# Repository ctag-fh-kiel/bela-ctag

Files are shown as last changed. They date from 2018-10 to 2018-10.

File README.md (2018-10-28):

## Resources regarding [CTAG-audio](http://ctag-audio.de/) capes for BeagleBone single board computers.

See [Wiki](https://github.com/ctag-fh-kiel/bela-ctag/wiki) for getting started with native Linux applications and CTAG multi-audio boards.

*CTAG multi-audio IO capes are compatible with the ultra-low-latency [Bela platform](http://bela.io/) and are available via [Bela's online shop](https://shop.bela.io/ctag).*

## Open source hardware resources include: 
- Schematic in pdf 
- Kicad 4.0.7 project data (PCB does not contain routed copper layers at this point --> will be added after some time together with BOM etc.)
- Licensed under [cc-by-nc-sa-4.0](https://creativecommons.org/licenses/by-nc-sa/4.0)

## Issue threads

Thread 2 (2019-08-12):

PCB copper layers and BOM

darabi, 2019-08-12:
Are you still planning to publish the BOM and the PCB copper layers, as stated in the README?

Thanks!

ctag-fh-kiel, 2019-08-19:
Hi, thanks for your interest. We haven't discussed a timing yet...

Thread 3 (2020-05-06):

Connecting a Potentiometer via SPI Using CTAG Beast in non-BELA mode

tonylangley, 2020-05-06:
Hi,

I'm trying to interface a 10K potentiometer via a MCP3008 ADC over SPI to the Beaglebone Black running the [ctag_bone_debian_v0.1.2.img](https://github.com/ctag-fh-kiel/bela-ctag/releases/tag/v0.1.2) release.

Will this be possible or should I interface the potentiometer a different way?

Thanks in advance, Tony

ctag-fh-kiel, 2020-05-06:
Hi Tony,
You should be able to use SPI with the standard (non-bela) image. The audio codec uses bit-banged SPI through GPIO freeing up the HW SPI peripheral. If you are on the bela image SPI is blocked by bela for ADC/DAC.

Best,
Robert

tonylangley, 2020-05-06:
Thanks Robert. That’s good to know the SPI bus is free in this mode.

Any chance you could point me to any info on how to enable the SPI on this [ctag_bone_debian_v0.12](https://github.com/ctag-fh-kiel/bela-ctag/releases/tag/v0.1.2) release? I tried a few ways of doing this by updating the /boot/uEnv.txt file but couldn’t work it out!

Thanks, Tony

tonylangley, 2020-05-07:
I was able to get SPI running with the following:

`sudo sh -c "echo 'BB-SPIDEV0' > /sys/devices/platform/bone_capemgr/slots"`

tonylangley, 2020-05-07:
So I'm able to get SPI running temporarily using the command above, but I'm unable to get the SPIDEV0 device to load at boot without commenting out the following line in /boot/uEnv.txt

`dtb=am335x-boneblack-ctag-face.dtb`

This line is creating a device-tree-override which seems to prevent any subsequent uboot_overlay_options to take effect.

Once I comment this out, I can verify the SPI devices as follows:

`ls -al /dev/spi*`

As I want to use both the CTAG Beast and SPI, do you have any suggestions on how can I enable this at boot time?

henrix, 2020-05-11:
Hi,

A workaround for this would be to automatically execute the bone cape manager script

> sh -c "echo 'BB-SPIDEV0' > /sys/devices/platform/bone_capemgr/slots"

 via rc.local.

You can find some information about rc.local [here](https://www.raspberrypi.org/documentation/linux/usage/rc-local.md).

Another solution would be to enable SPIDEV in the base device tree am335x-boneblack-ctag-face.dtb. However, this would require to create a different base device trees for each required hardware configuration.

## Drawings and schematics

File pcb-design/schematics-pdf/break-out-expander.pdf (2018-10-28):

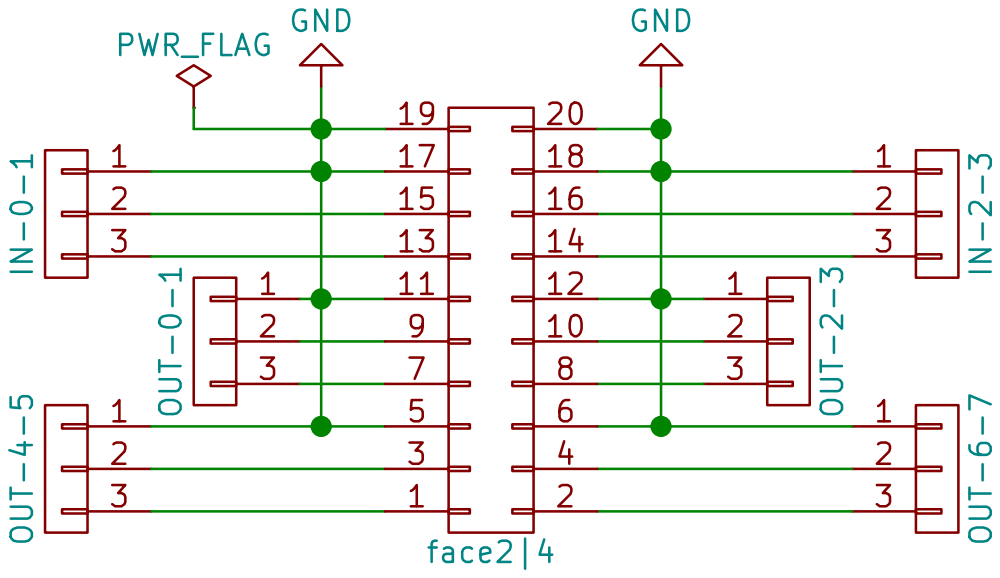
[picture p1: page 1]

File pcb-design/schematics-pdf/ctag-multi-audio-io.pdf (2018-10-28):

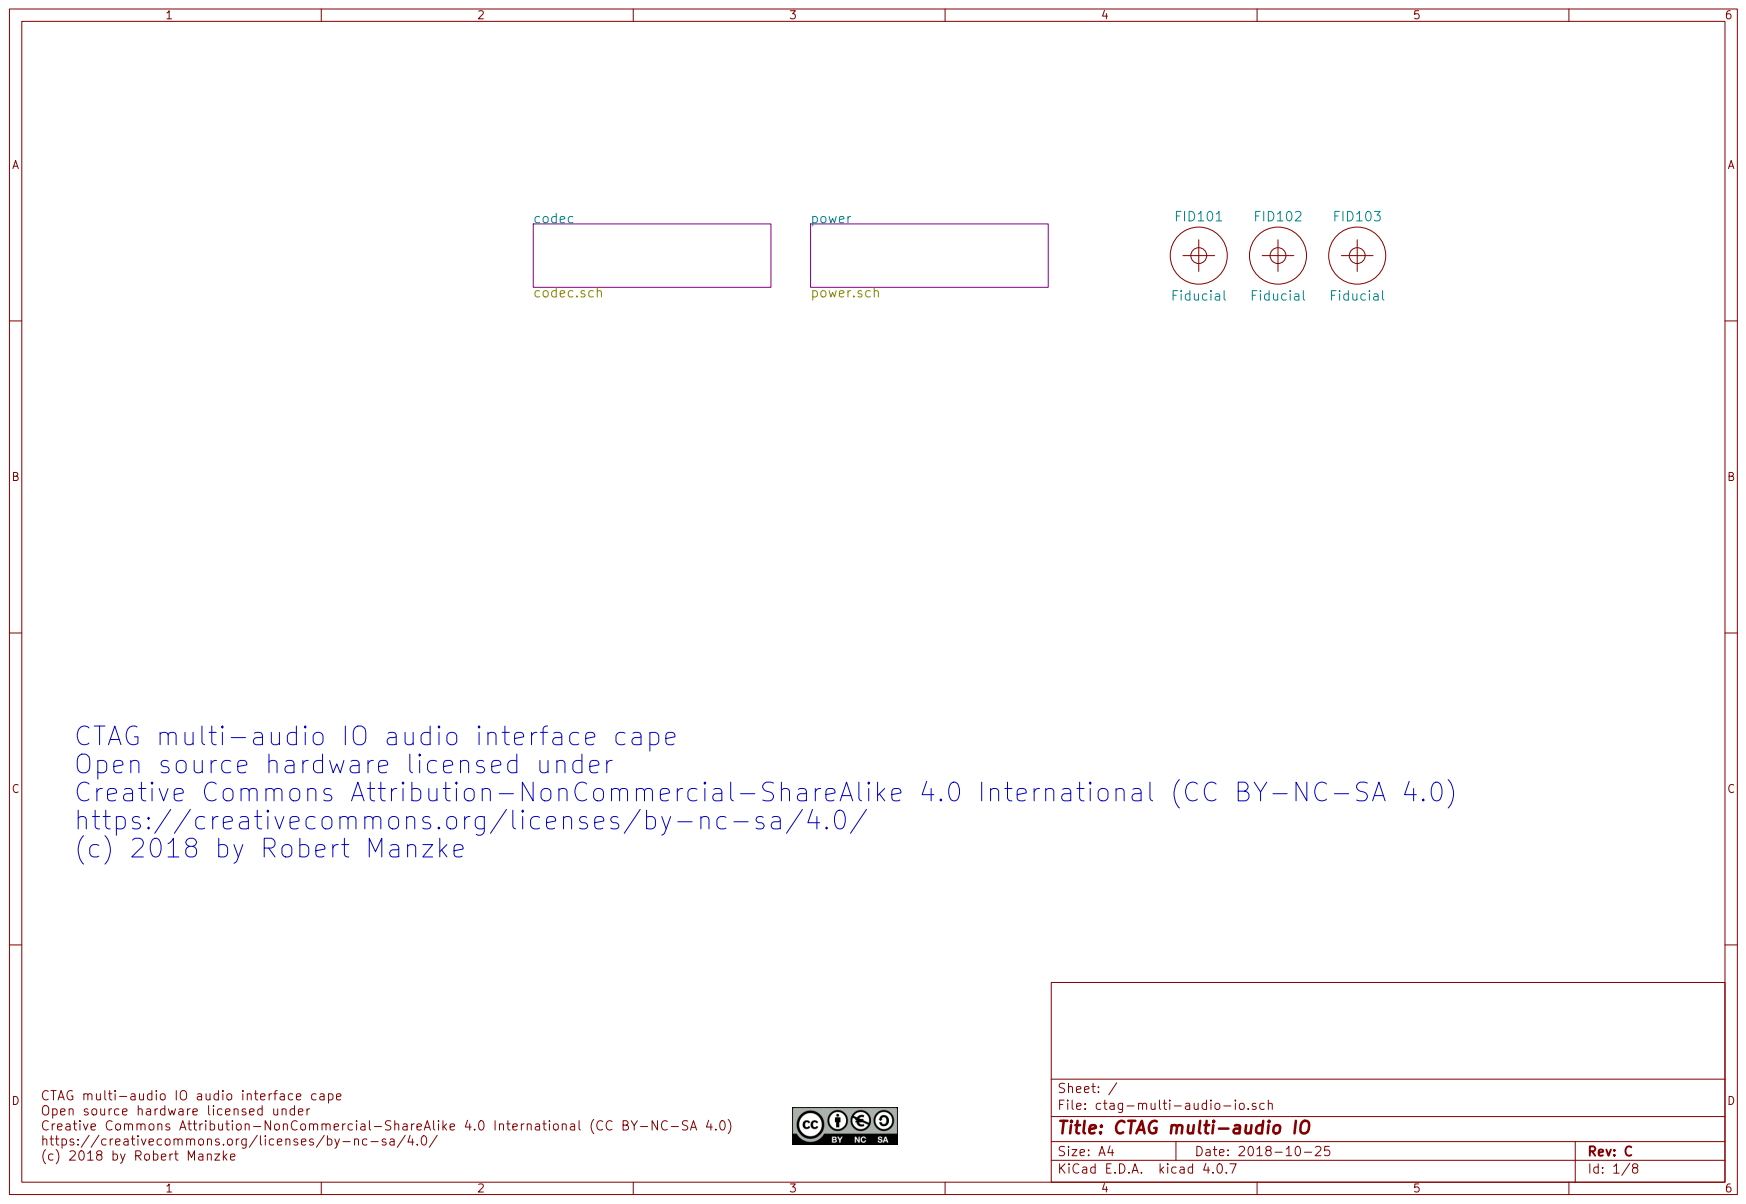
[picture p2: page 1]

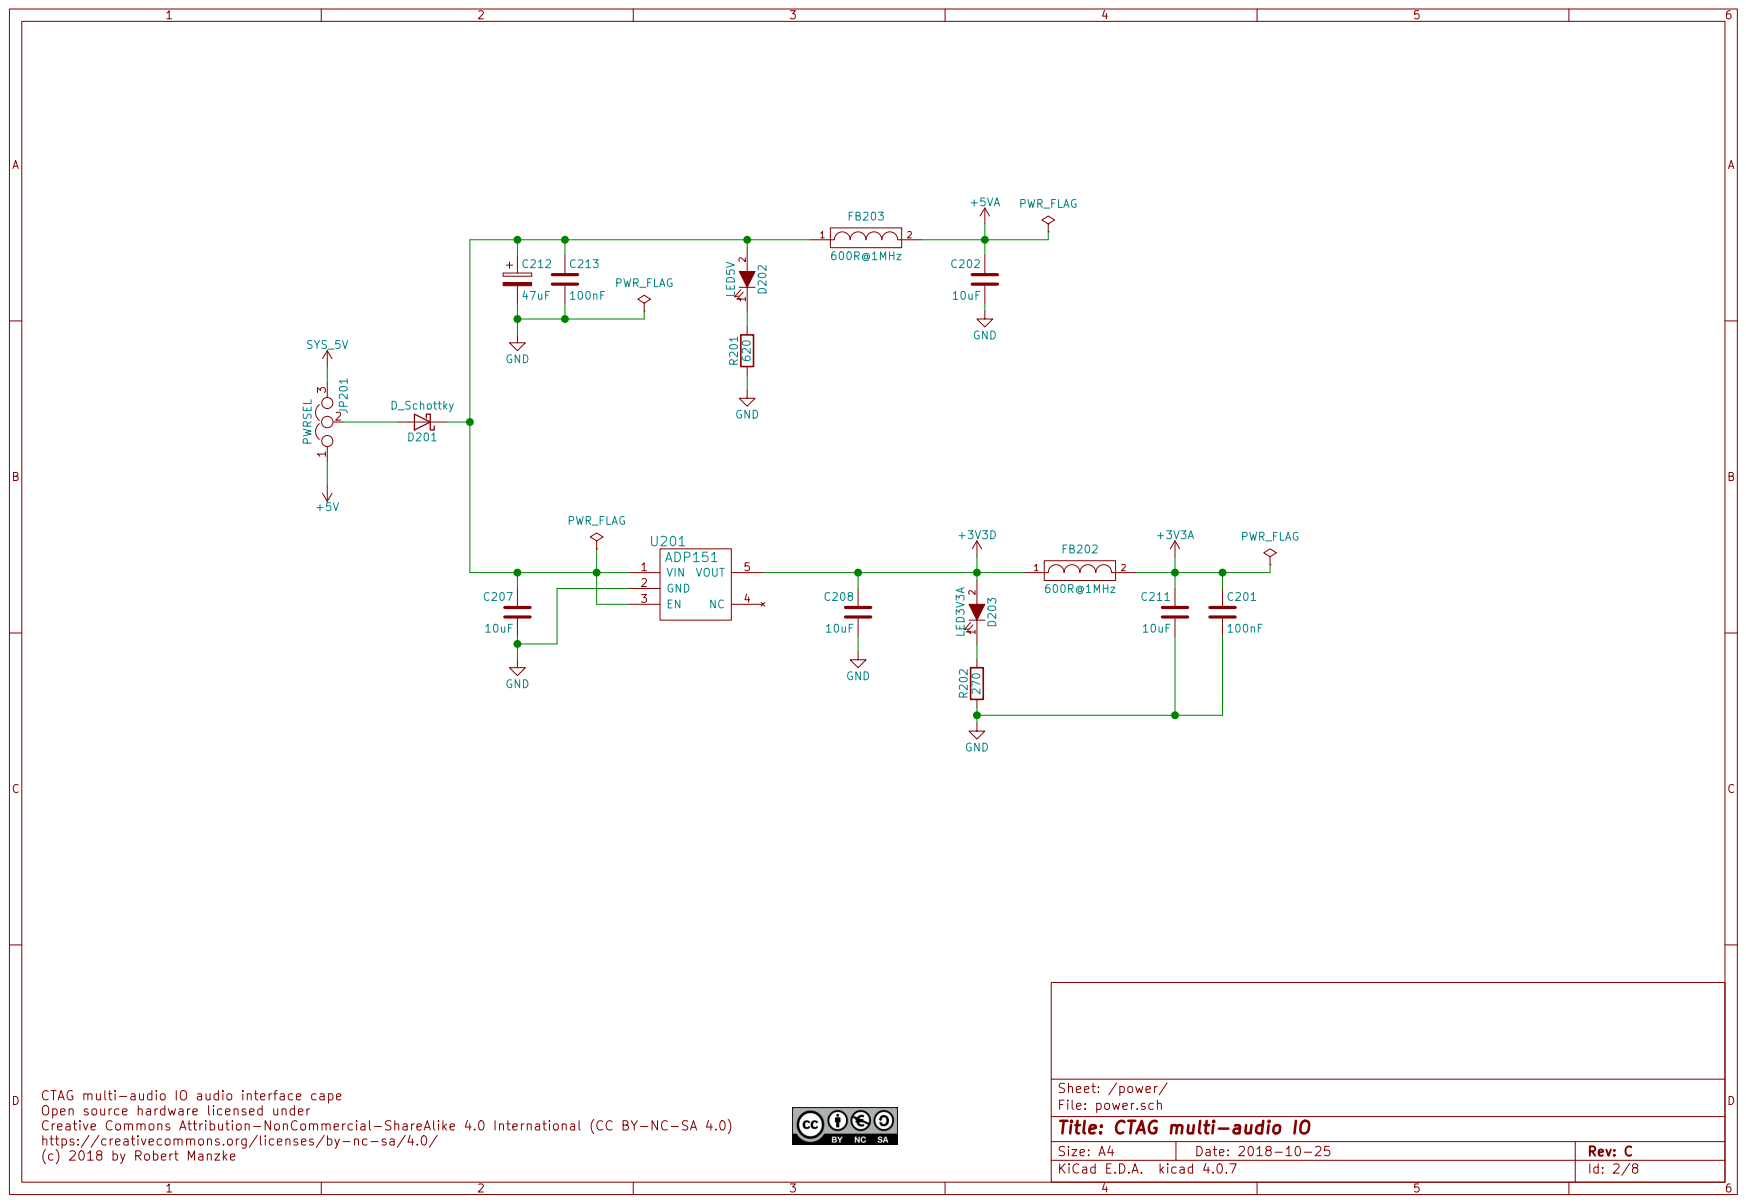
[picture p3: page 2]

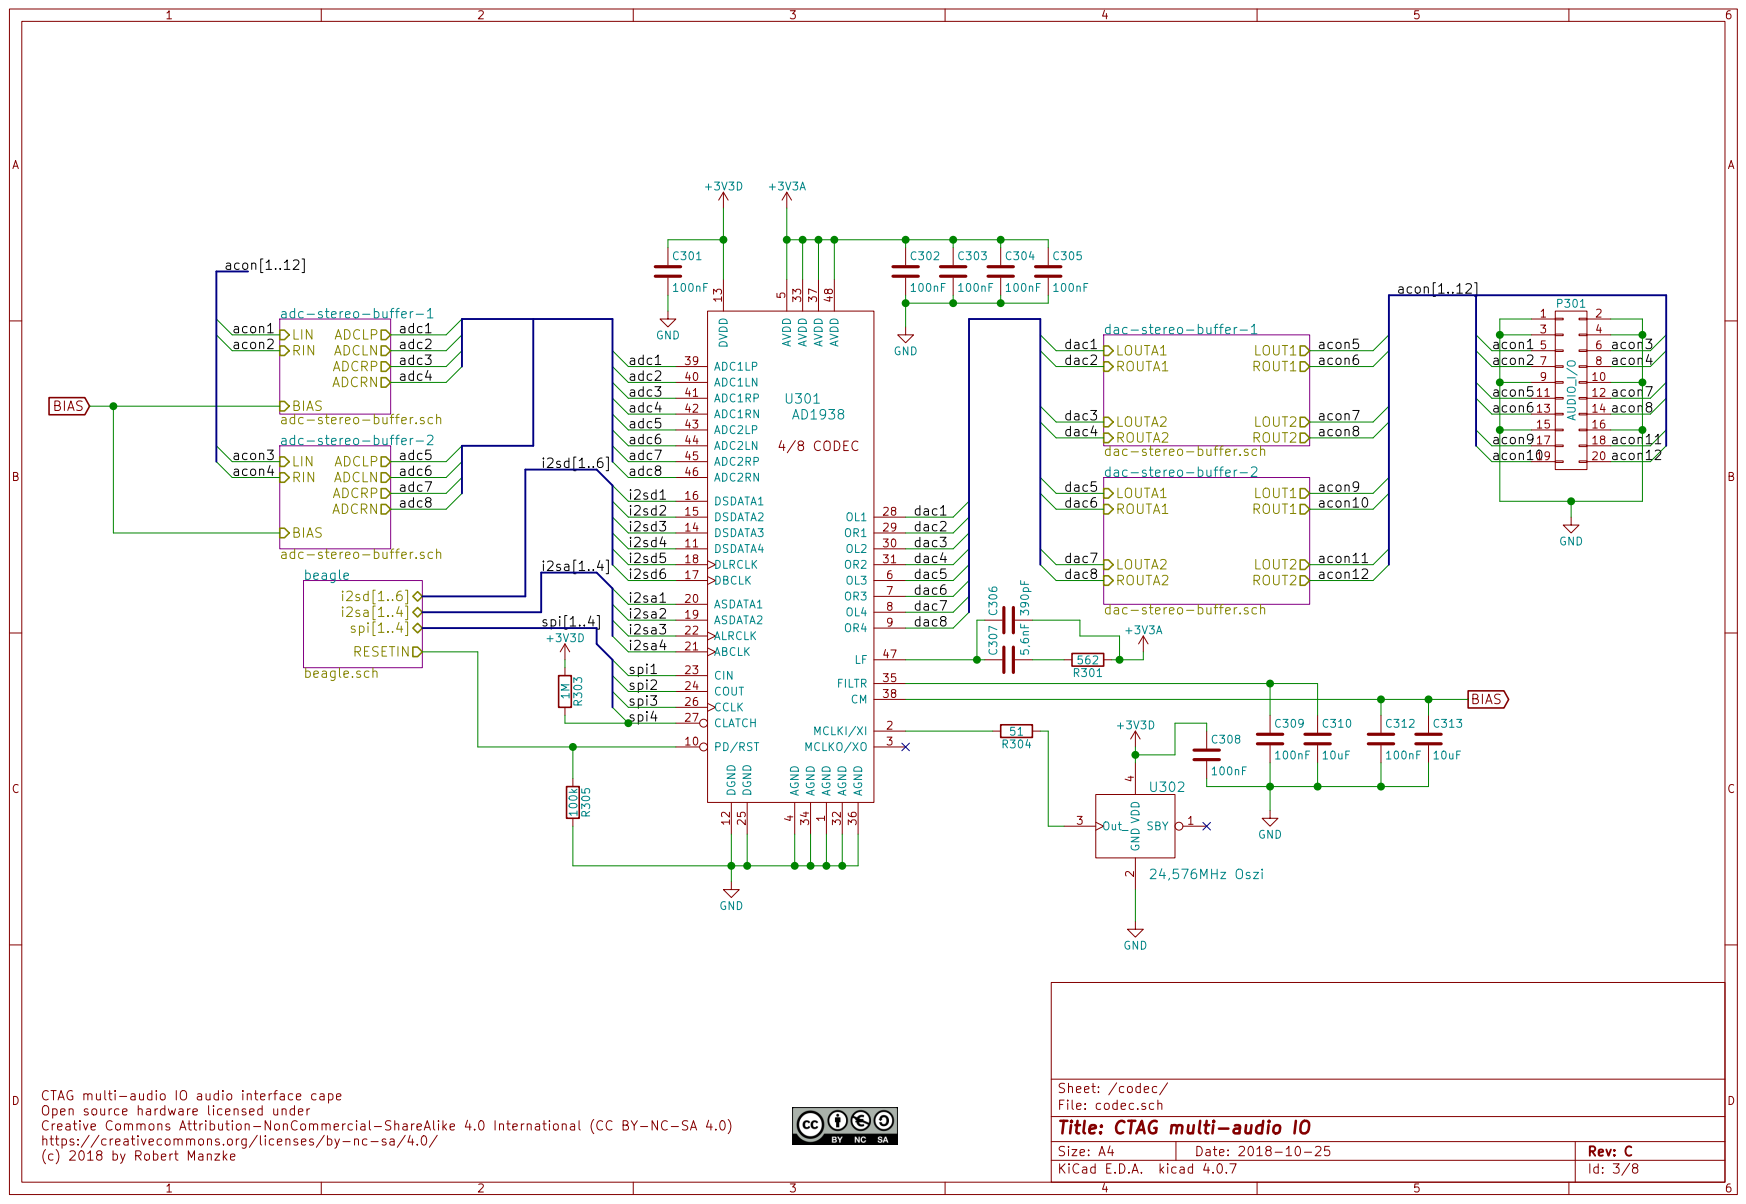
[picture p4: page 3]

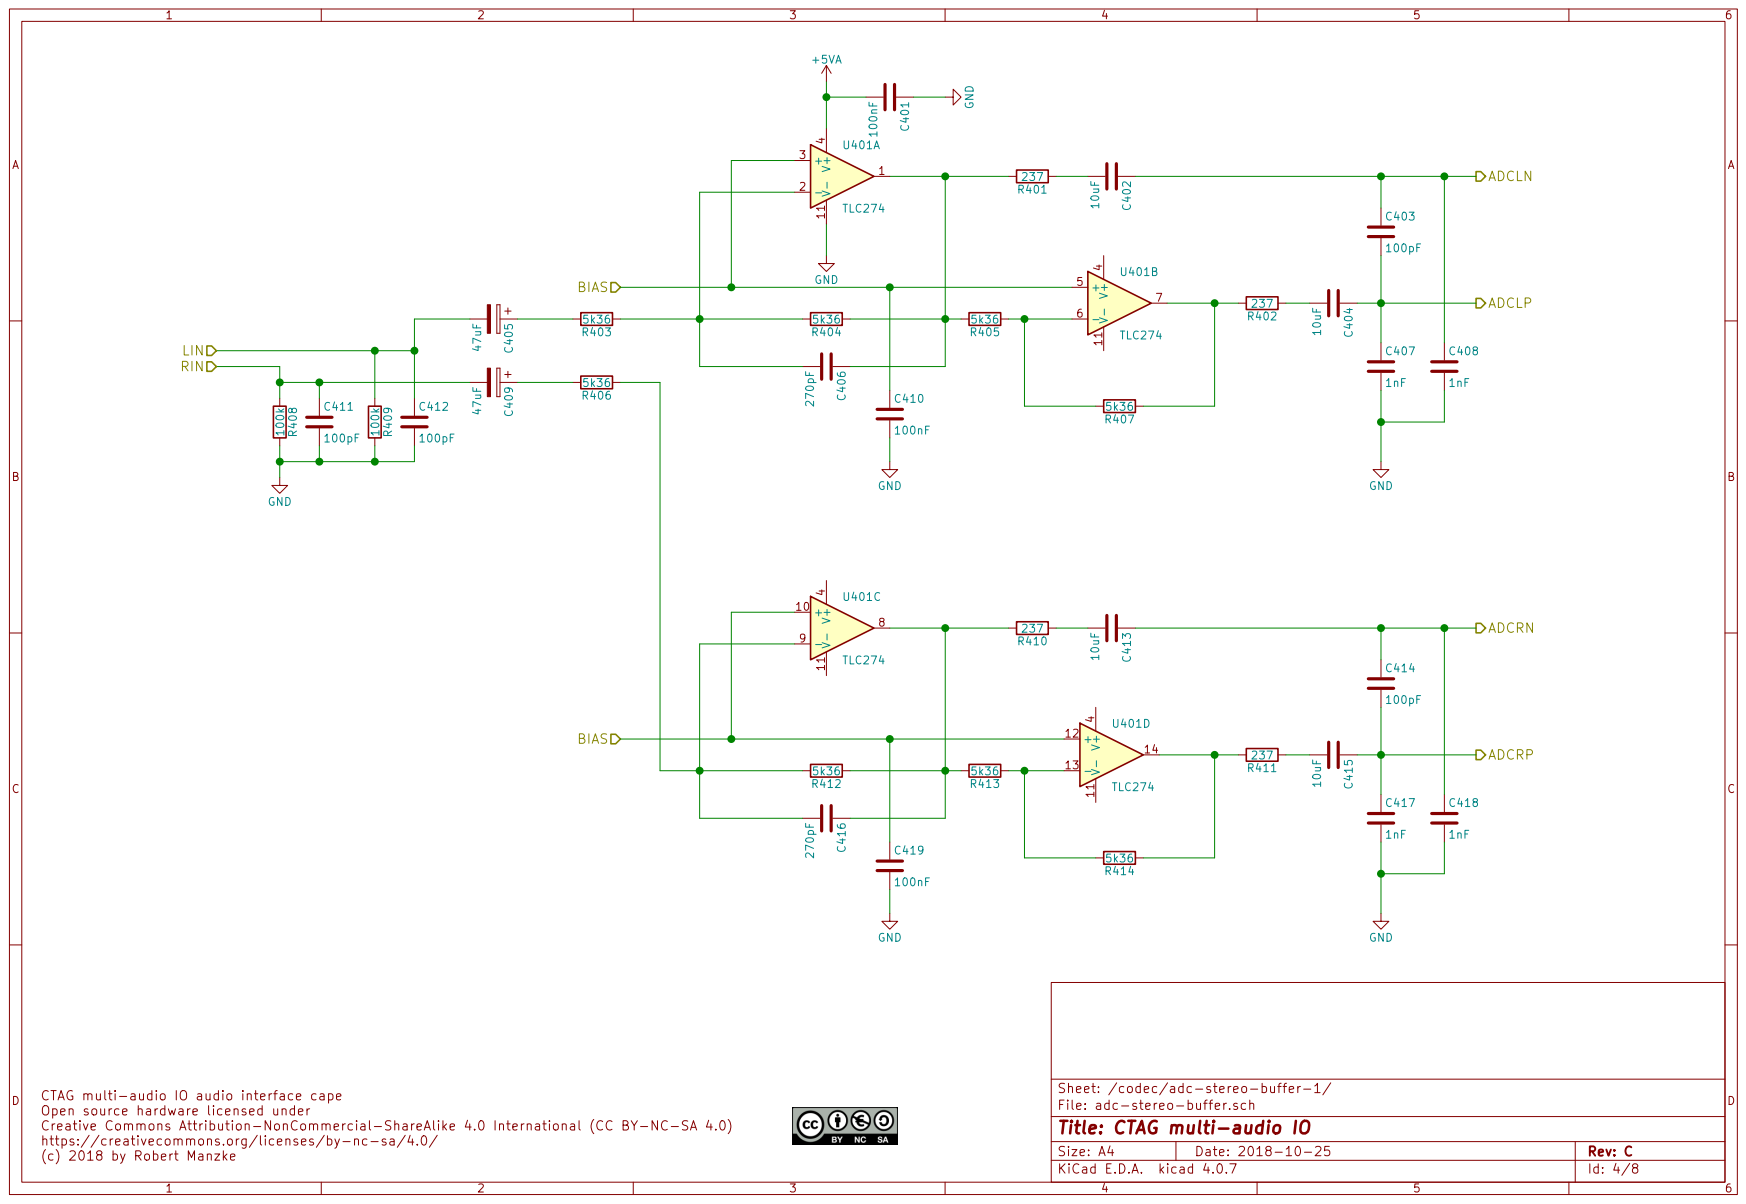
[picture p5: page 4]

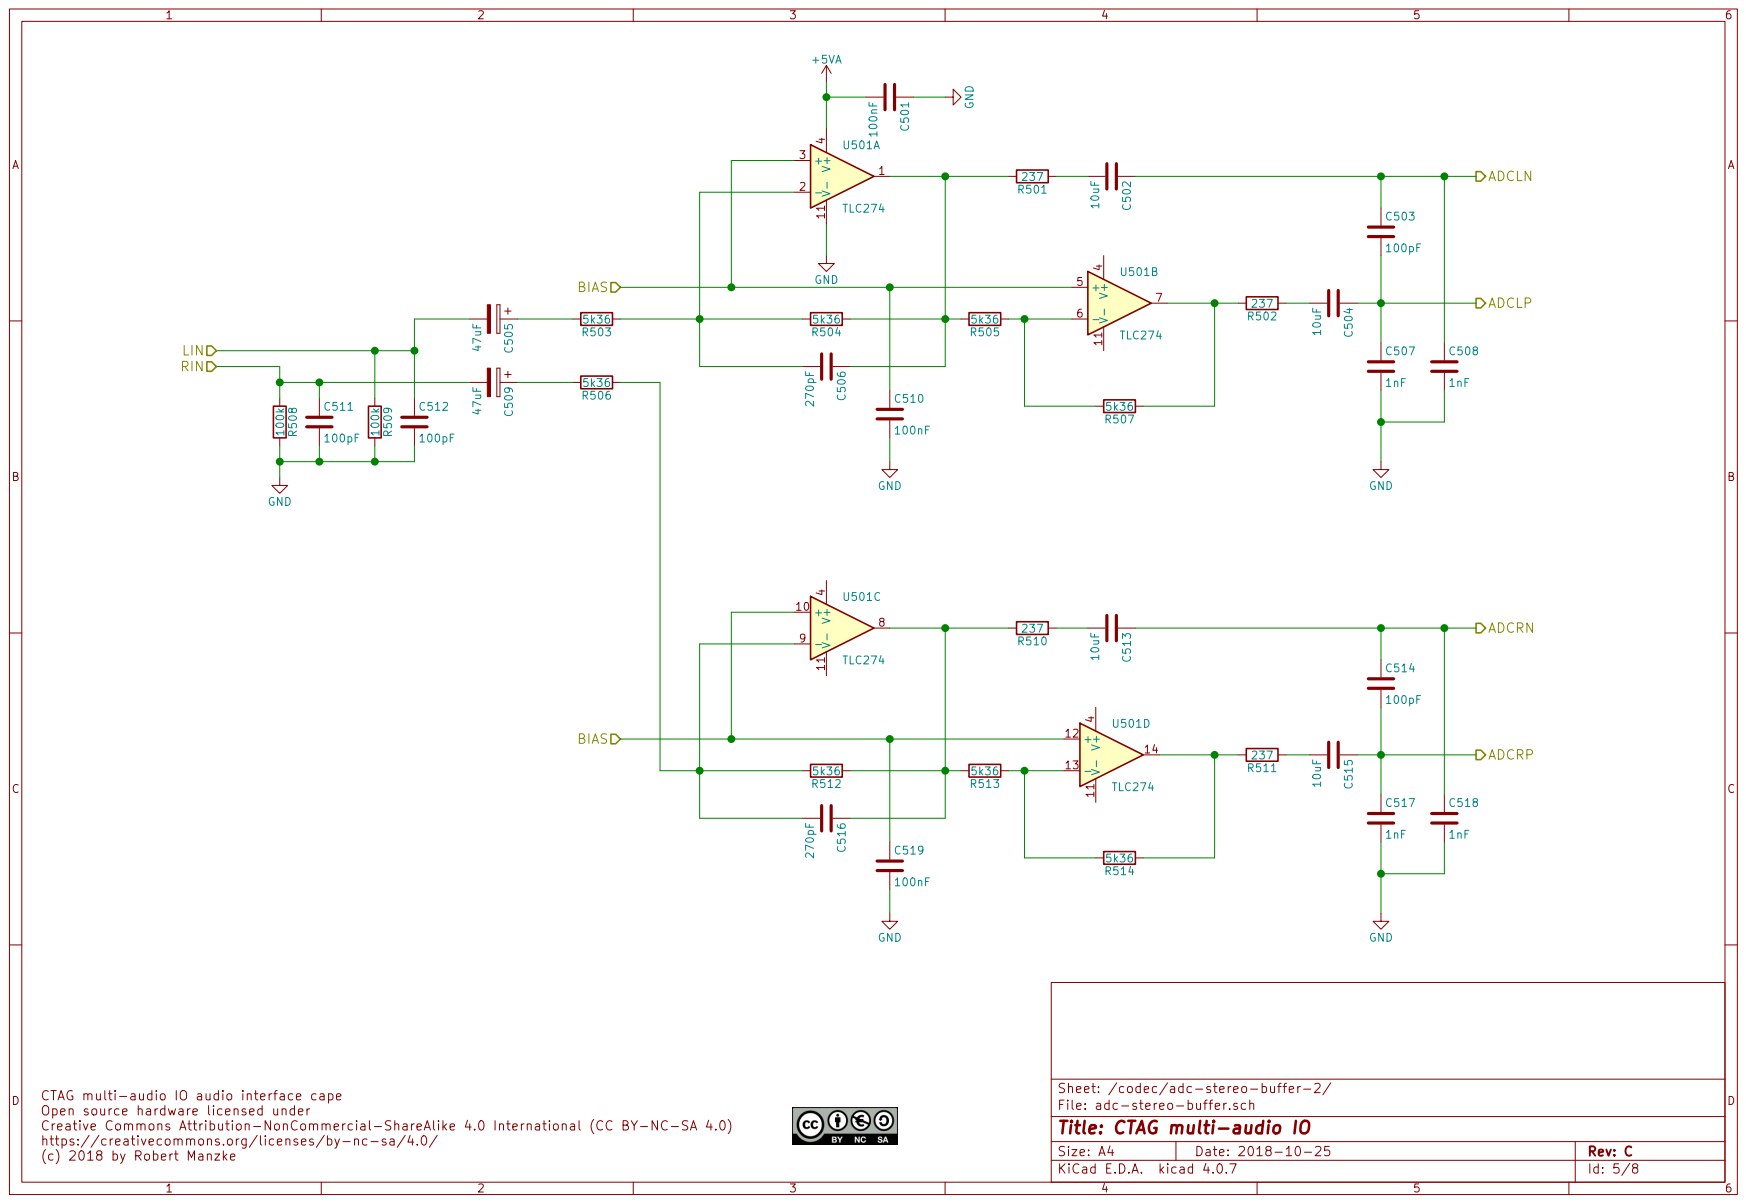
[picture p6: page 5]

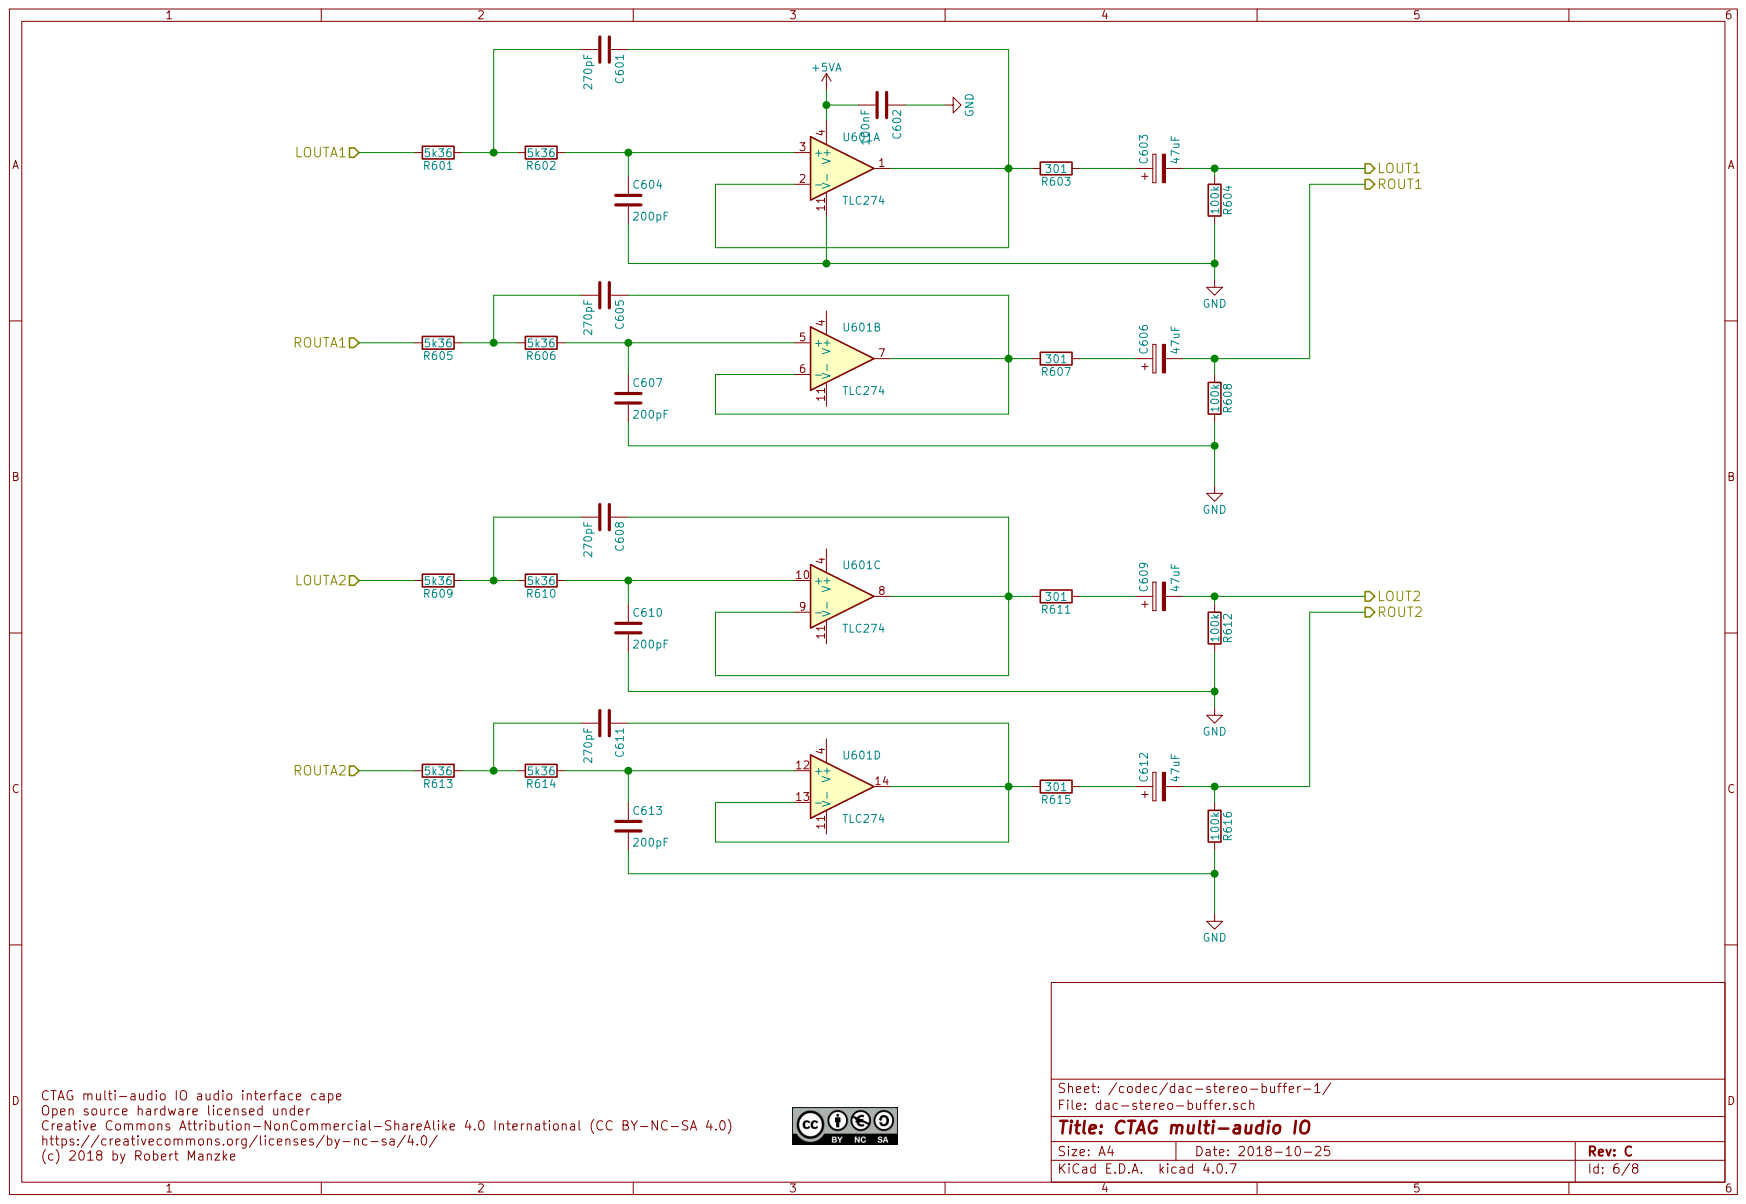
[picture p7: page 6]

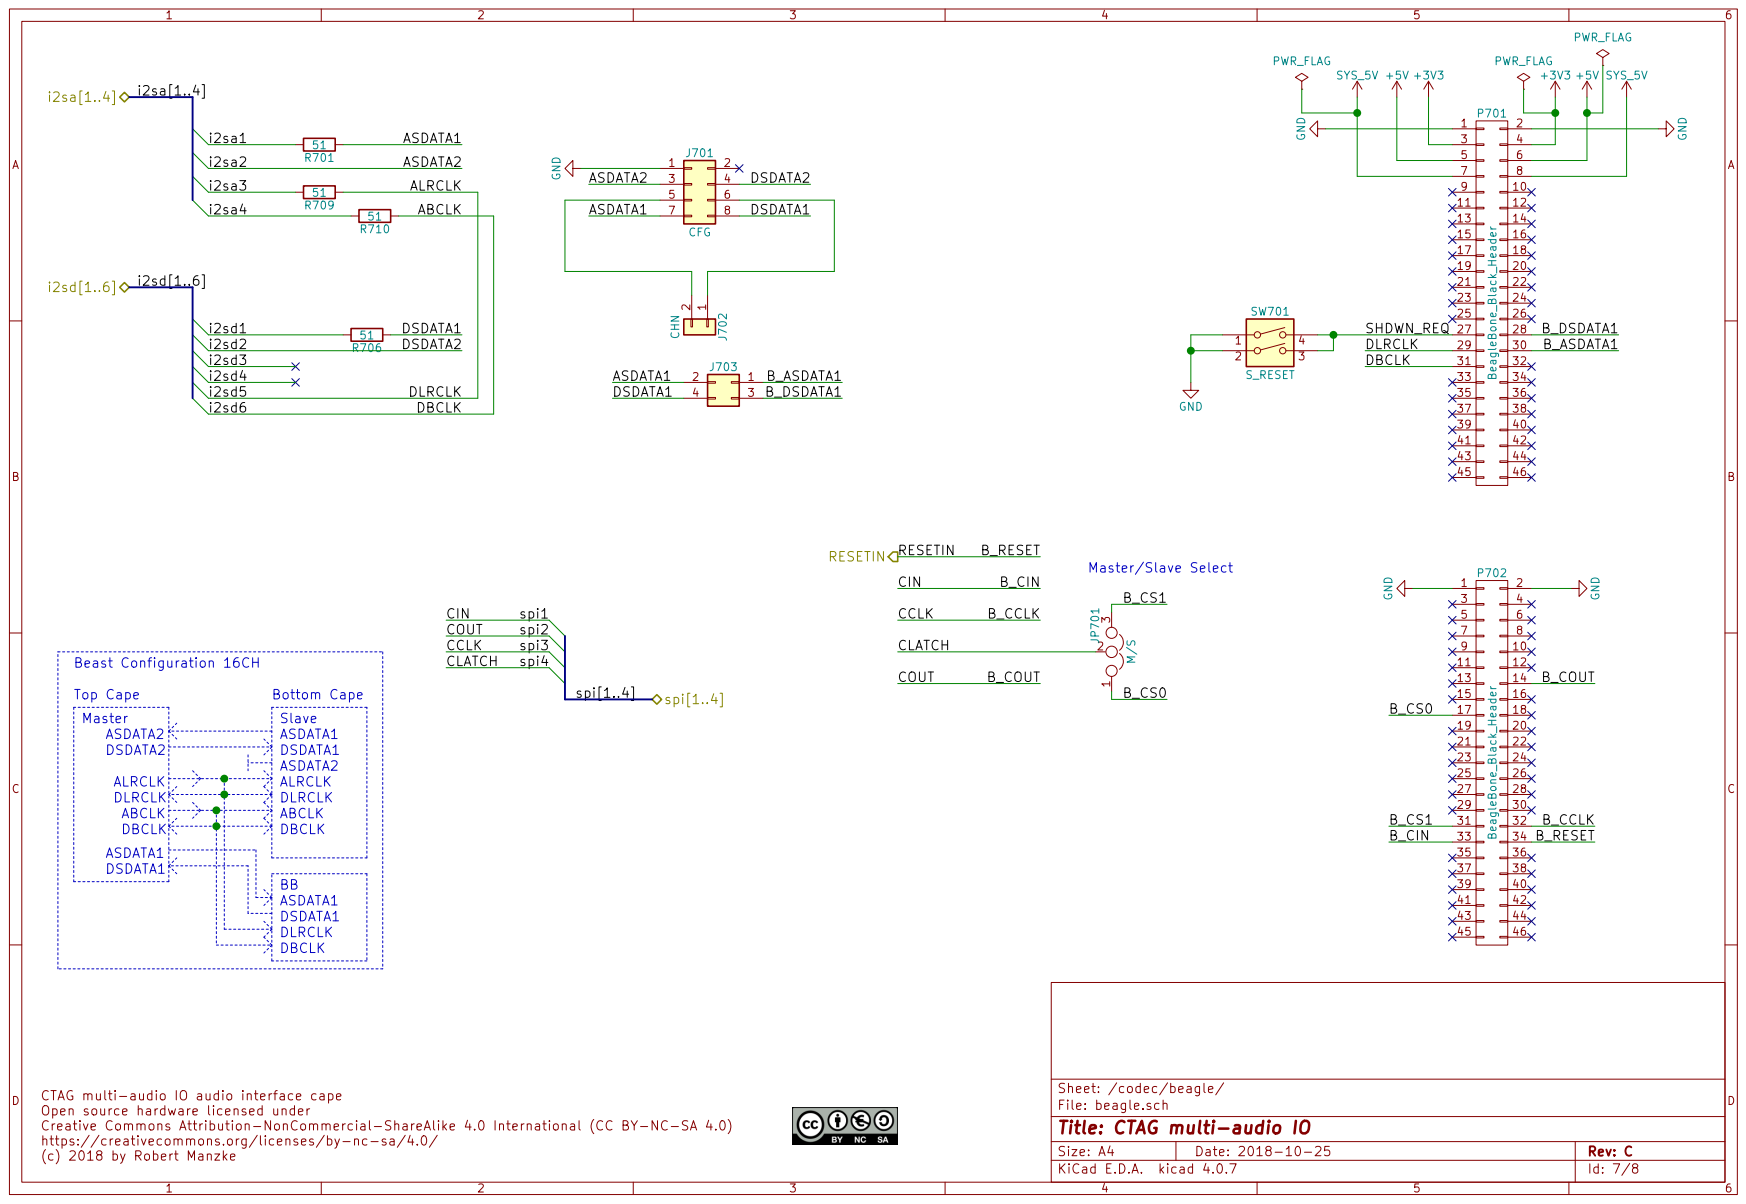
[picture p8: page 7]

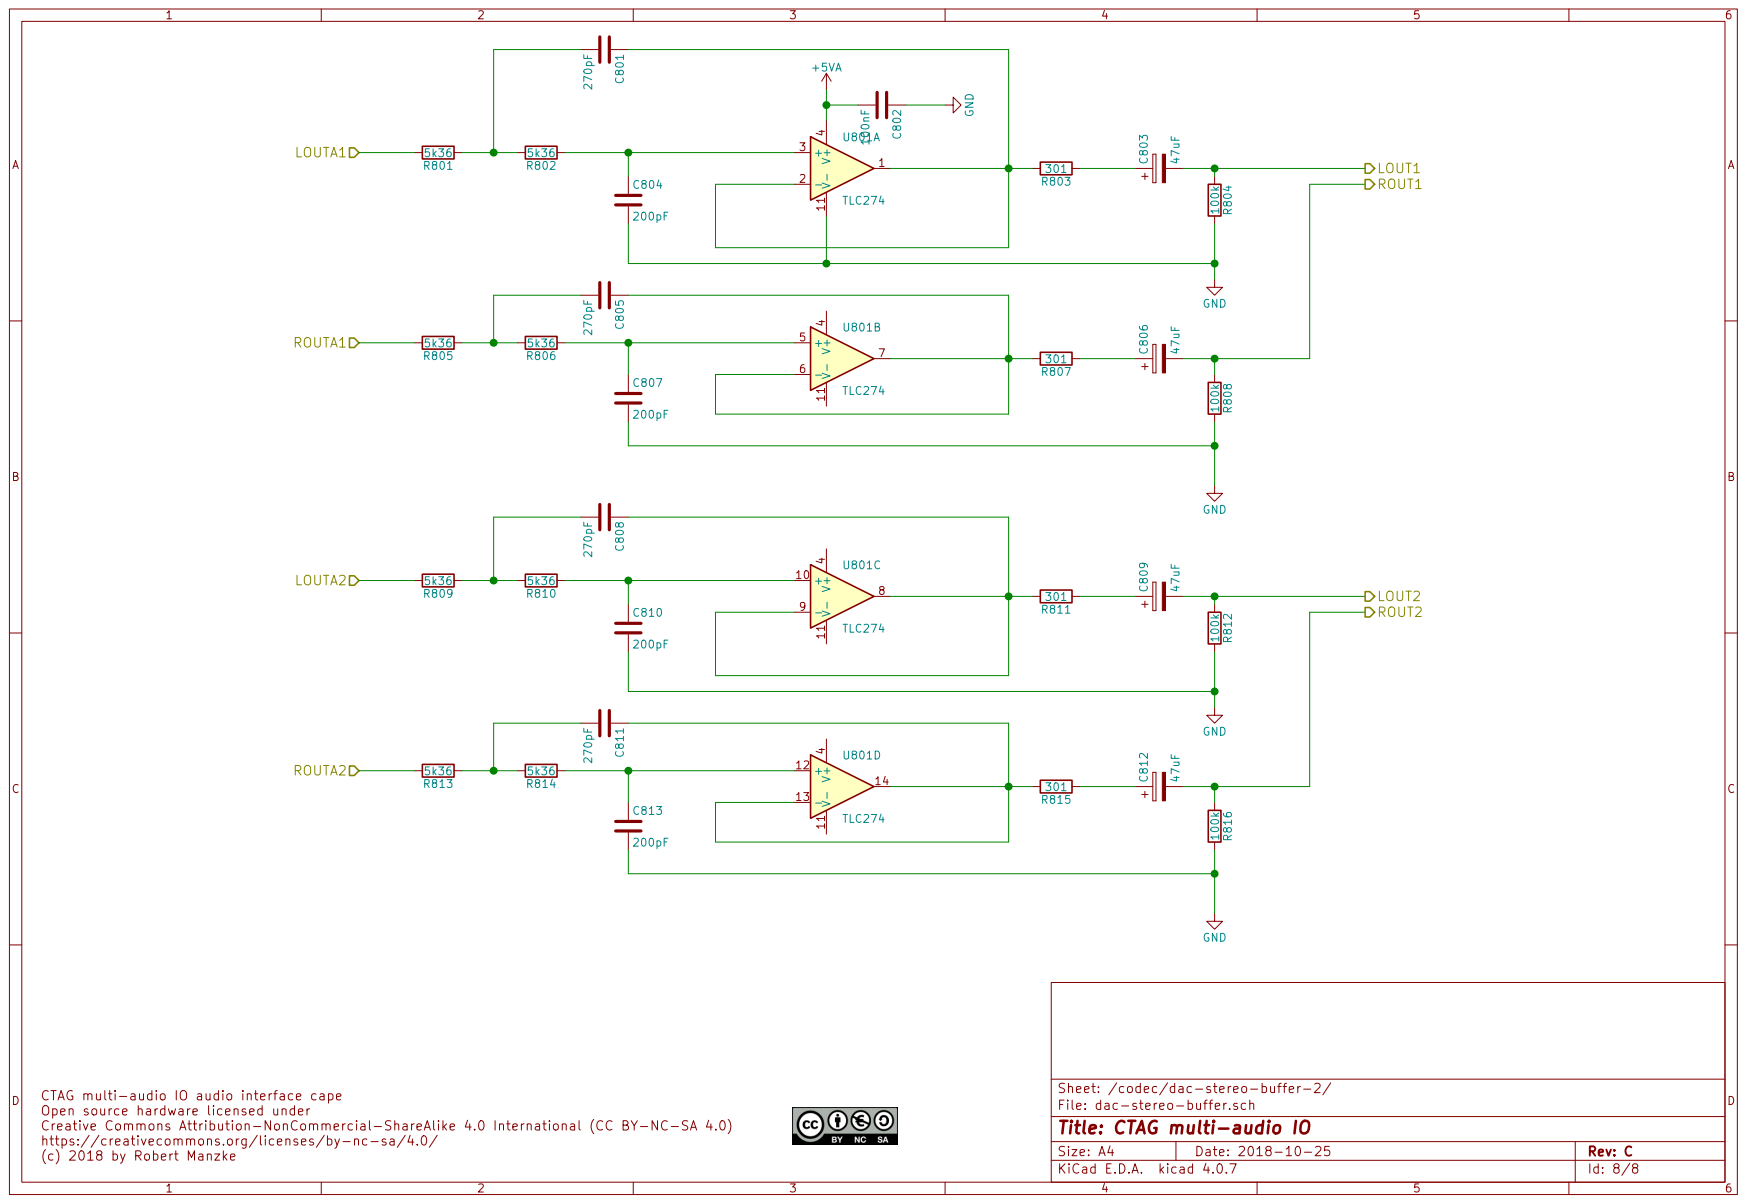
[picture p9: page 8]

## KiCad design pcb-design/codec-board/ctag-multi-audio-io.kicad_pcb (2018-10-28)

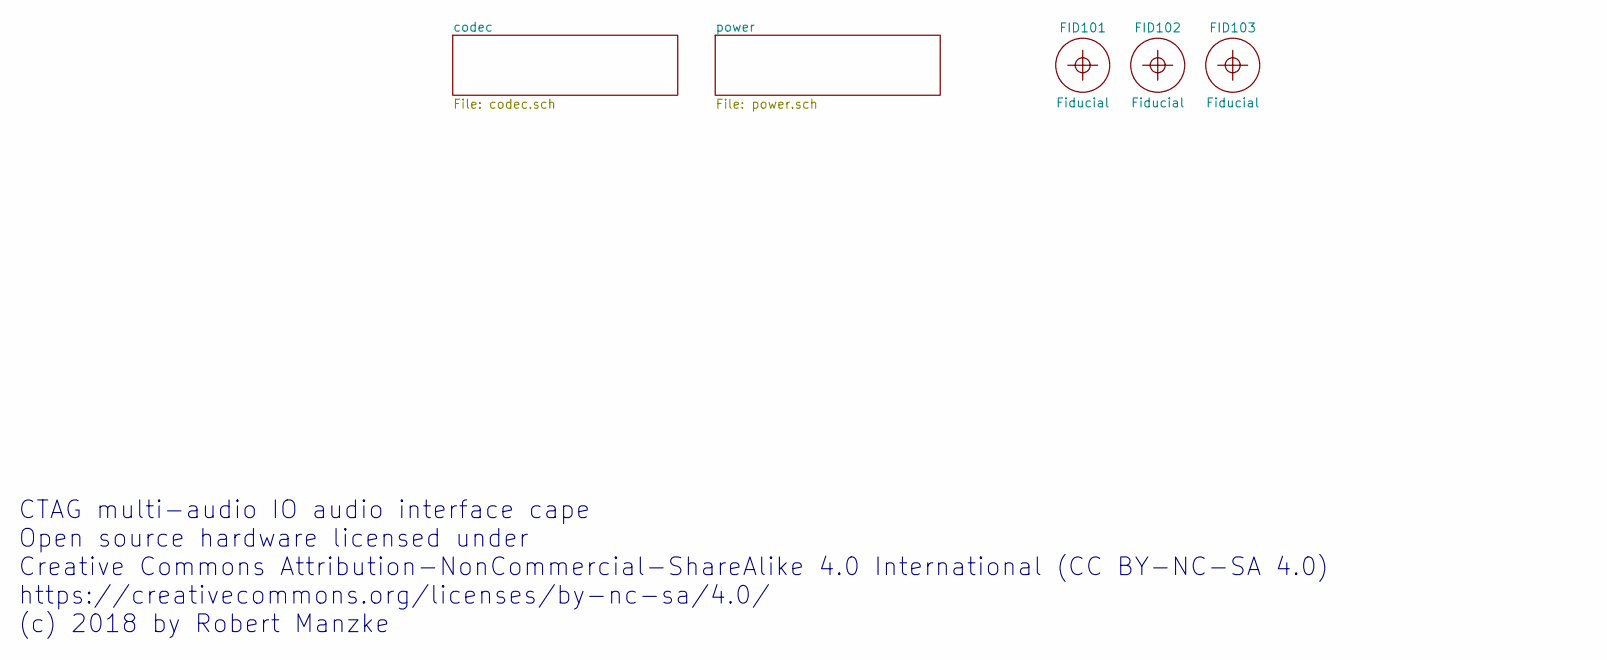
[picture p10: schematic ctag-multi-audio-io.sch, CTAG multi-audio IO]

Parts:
FID101, FID102, FID103: Fiducial; Fiducial_1mm_Dia_2.54mm_Outer_CopperTop

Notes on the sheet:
CTAG multi-audio IO audio interface cape Open source hardware licensed under Creative Commons Attribution-NonCommercial-ShareAlike 4.0 International (CC BY-NC-SA 4.0) https://creativecommons.org/licenses/by-nc-sa/4.0/ (c) 2018 by Robert Manzke

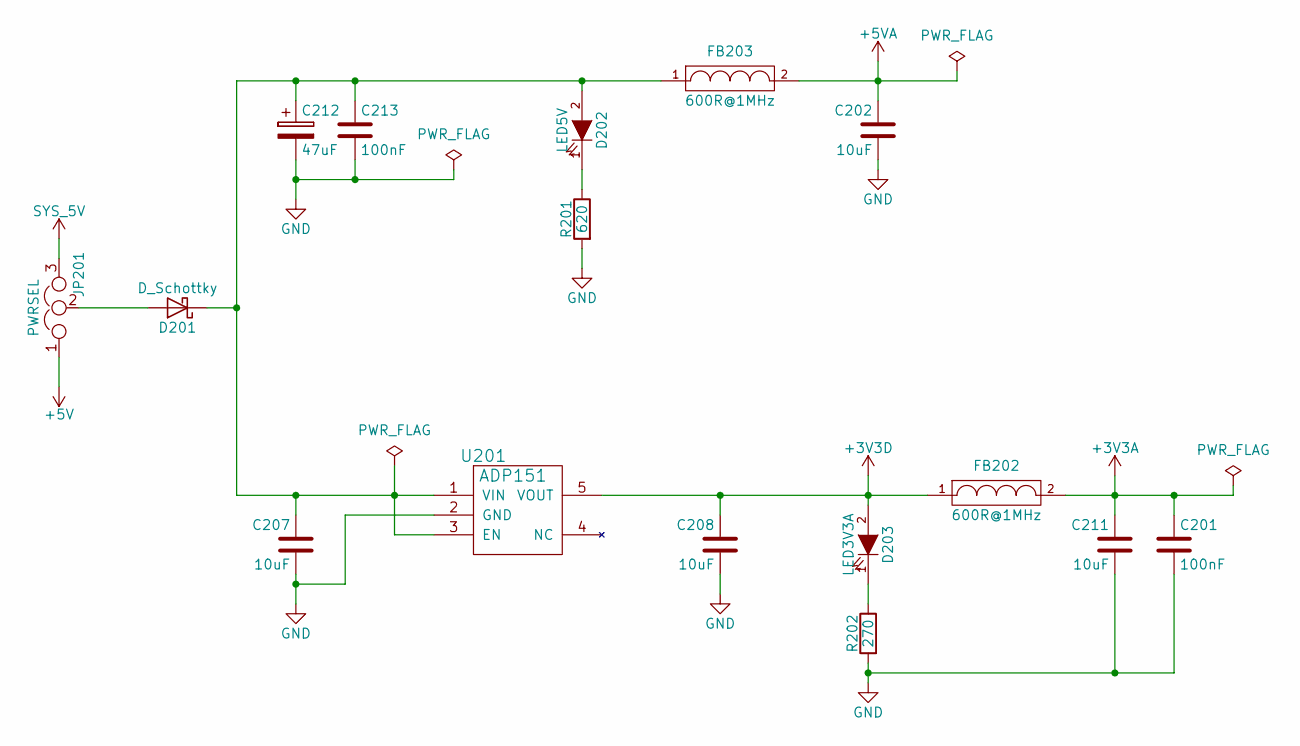
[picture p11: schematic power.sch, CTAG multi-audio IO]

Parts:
C201, C213: 100nF; C_0603
C202, C207, C208, C211: 10uF; C_0805
C212: 47uF; TantalC_SizeA_EIA-3216_Reflow
D201: D_Schottky; SOD-123
D202: LED5V; LED-0603
D203: LED3V3A; LED-0603
FB202, FB203: 600R@1MHz; C_0805
JP201: PWRSEL; Pin_Header_Straight_1x03
R201: 620; C_0603
R202: 270; C_0603
U201: ADP151; TSOT-23-5

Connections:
+3V3A: C201.1, C211.1, FB202.2; also elsewhere on the board
+3V3D: C208.1, D203.2 (A), FB202.1, U201.5 (VOUT); also elsewhere on the board
+5V: JP201.1; also elsewhere on the board
+5VA: C202.1, FB203.2; also elsewhere on the board
GND: C201.2, C202.2, C207.2, C208.2, C211.2, C212.2, C213.2, R201.2, R202.2, U201.2 (GND); also elsewhere on the board
unnamed: C207.1, C212.1, C213.1, D201.1 (K), D202.2 (A), FB203.1, U201.1 (VIN), U201.3 (EN)
unnamed: D201.2 (A), JP201.2
unnamed: D202.1 (K), R201.1
unnamed: D203.1 (K), R202.1
SYS_5V: JP201.3; also elsewhere on the board

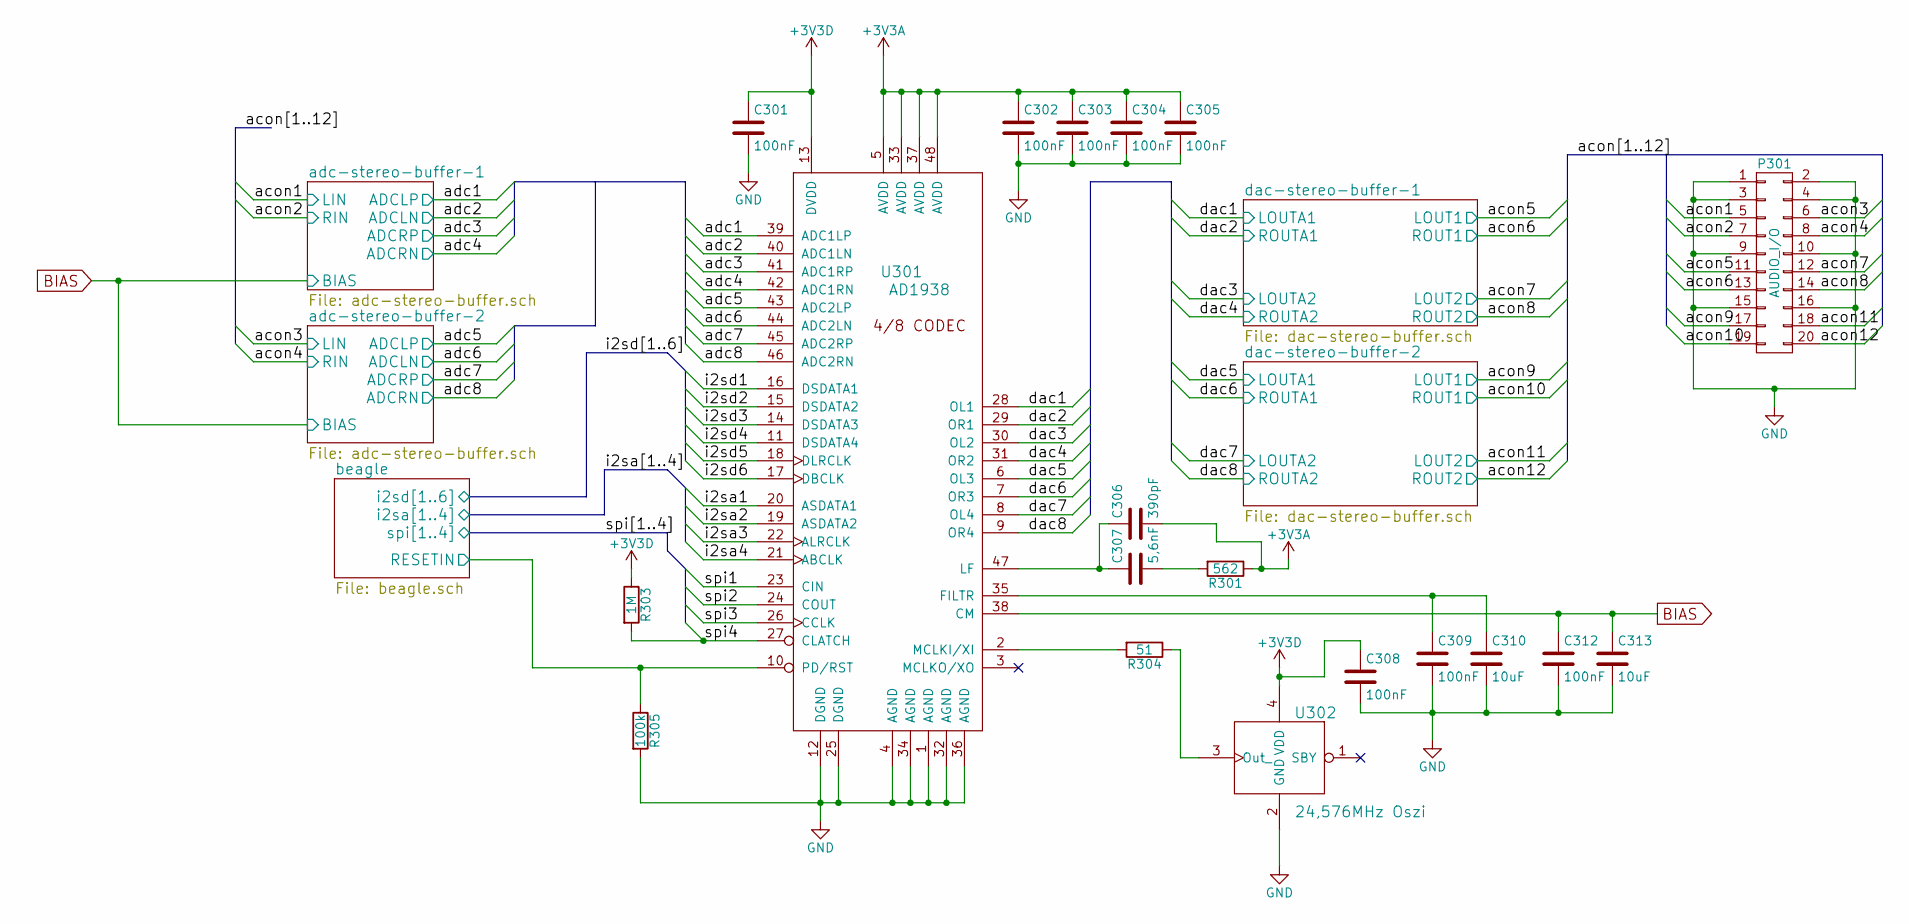
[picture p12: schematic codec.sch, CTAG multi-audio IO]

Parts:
C301, C302, C303, C304, C305, C308, C309, C312: 100nF; C_0603
C306: 390pF; C_0603
C307: 5,6nF; C_0603
C310, C313: 10uF; C_0805
P301: AUDIO_I/O; Pin_Header_Angled_2x10
R301: 562; C_0603
R303: 1M; C_0603
R304: 51; C_0603
R305: 100k; C_0603
U301: AD1938; LQFP-48_7x7mm_Pitch0.5mm
U302: 24,576MHz Oszi; Oszi_3.2x2.5mm

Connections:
+3V3A: C302.1, C303.1, C304.1, C305.1, C306.2, R301.1, U301.5 (AVDD), U301.33 (AVDD), U301.37 (AVDD), U301.48 (AVDD); also elsewhere on the board
+3V3D: C301.1, C308.1, R303.1, U301.13 (DVDD), U302.4 (VDD); also elsewhere on the board
/codec/acon1: P301.5; also elsewhere on the board
/codec/acon2: P301.7; also elsewhere on the board
/codec/acon3: P301.6; also elsewhere on the board
/codec/acon4: P301.8; also elsewhere on the board
/codec/acon5: P301.11; also elsewhere on the board
/codec/acon6: P301.13; also elsewhere on the board
/codec/acon7: P301.12; also elsewhere on the board
/codec/acon8: P301.14; also elsewhere on the board
/codec/acon9: P301.17; also elsewhere on the board
/codec/acon10: P301.19; also elsewhere on the board
/codec/acon11: P301.18; also elsewhere on the board
/codec/acon12: P301.20; also elsewhere on the board
/codec/adc1: U301.39 (ADC1LP); also elsewhere on the board
/codec/adc2: U301.40 (ADC1LN); also elsewhere on the board
/codec/adc3: U301.41 (ADC1RP); also elsewhere on the board
/codec/adc4: U301.42 (ADC1RN); also elsewhere on the board
/codec/adc5: U301.43 (ADC2LP); also elsewhere on the board
/codec/adc6: U301.44 (ADC2LN); also elsewhere on the board
/codec/adc7: U301.45 (ADC2RP); also elsewhere on the board
/codec/adc8: U301.46 (ADC2RN); also elsewhere on the board
/codec/beagle/RESETIN: R305.1, U301.10 (PD/RST); also elsewhere on the board
/codec/dac1: U301.28 (OL1); also elsewhere on the board
/codec/dac2: U301.29 (OR1); also elsewhere on the board
/codec/dac3: U301.30 (OL2); also elsewhere on the board
/codec/dac4: U301.31 (OR2); also elsewhere on the board
/codec/dac5: U301.6 (OL3); also elsewhere on the board
/codec/dac6: U301.7 (OR3); also elsewhere on the board
/codec/dac7: U301.8 (OL4); also elsewhere on the board
/codec/dac8: U301.9 (OR4); also elsewhere on the board
/codec/i2sa1: U301.20 (ASDATA1); also elsewhere on the board
/codec/i2sa2: U301.19 (ASDATA2); also elsewhere on the board
/codec/i2sa3: U301.22 (ALRCLK); also elsewhere on the board
/codec/i2sa4: U301.21 (ABCLK); also elsewhere on the board
/codec/i2sd1: U301.16 (DSDATA1); also elsewhere on the board
/codec/i2sd2: U301.15 (DSDATA2); also elsewhere on the board
/codec/i2sd3: U301.14 (DSDATA3)
/codec/i2sd4: U301.11 (DSDATA4)
/codec/i2sd5: U301.18 (DLRCLK); also elsewhere on the board
/codec/i2sd6: U301.17 (DBCLK); also elsewhere on the board
/codec/spi1: U301.23 (CIN); also elsewhere on the board
/codec/spi2: U301.24 (COUT); also elsewhere on the board
/codec/spi3: U301.26 (CCLK); also elsewhere on the board
/codec/spi4: R303.2, U301.27 (CLATCH); also elsewhere on the board
BIAS: C312.1, C313.1, U301.38 (CM); also elsewhere on the board
GND: C301.2, C302.2, C303.2, C304.2, C305.2, C308.2, C309.2, C310.2, C312.2, C313.2, P301.1, P301.2, P301.3, P301.4, P301.9, P301.10, P301.15, P301.16, R305.2, U301.1 (AGND), U301.4 (AGND), U301.12 (DGND), U301.25 (DGND), U301.32 (AGND), U301.34 (AGND), U301.36 (AGND), U302.2 (GND); also elsewhere on the board
unnamed: C306.1, C307.1, U301.47 (LF)
unnamed: C307.2, R301.2
unnamed: C309.1, C310.1, U301.35 (FILTR)
unnamed: R304.1, U302.3 (Out_)
unnamed: R304.2, U301.2 (MCLKI/XI)

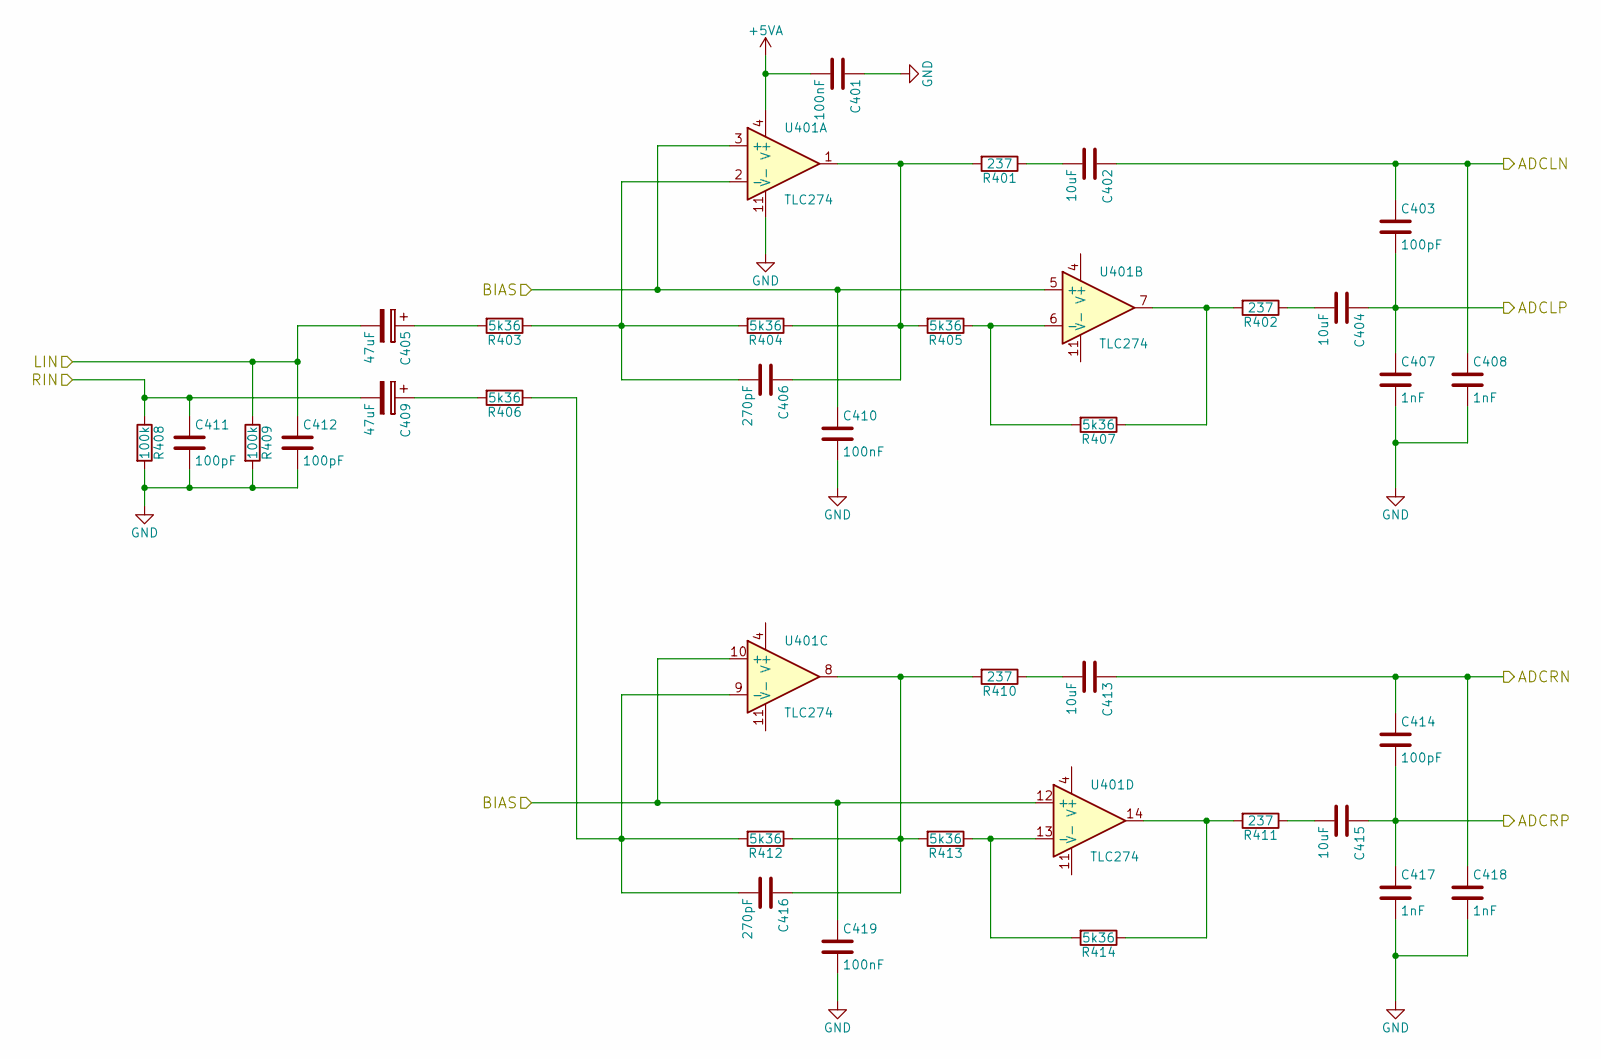
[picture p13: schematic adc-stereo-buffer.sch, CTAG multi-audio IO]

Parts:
C401, C410, C419: 100nF; C_0603
C402, C404, C413, C415: 10uF; C_0805
C403, C411, C412, C414: 100pF; C_0603
C405, C409: 47uF; TantalC_SizeA_EIA-3216_Reflow
C406, C416: 270pF; C_0603
C407, C408, C417, C418: 1nF; C_0603
R401, R402, R410, R411: 237; C_0603
R403, R404, R405, R406, R407, R412, R413, R414: 5k36; C_0603
R408, R409: 100k; C_0603
U401: TLC274; TSSOP-14_4.4x5mm_Pitch0.65mm

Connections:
+5VA: C401.2, U401.4 (V+); also elsewhere on the board
/codec/acon1: C405.2, C412.1, R409.1; also elsewhere on the board
/codec/acon2: C409.2, C411.1, R408.1; also elsewhere on the board
/codec/adc1: C403.2, C404.1, C407.1; also elsewhere on the board
/codec/adc2: C402.1, C403.1, C408.1; also elsewhere on the board
/codec/adc3: C414.2, C415.1, C417.1; also elsewhere on the board
/codec/adc4: C413.1, C414.1, C418.1; also elsewhere on the board
BIAS: C410.1, C419.1, U401.3 (+), U401.5 (+), U401.10 (+), U401.12 (+); also elsewhere on the board
GND: C401.1, C407.2, C408.2, C410.2, C411.2, C412.2, C417.2, C418.2, C419.2, R408.2, R409.2, U401.11 (V-); also elsewhere on the board
unnamed: C402.2, R401.1
unnamed: C404.2, R402.1
unnamed: C405.1, R403.2
unnamed: C406.1, R401.2, R404.1, R405.2, U401.1
unnamed: C406.2, R403.1, R404.2, U401.2 (-)
unnamed: C409.1, R406.2
unnamed: C413.2, R410.1
unnamed: C415.2, R411.1
unnamed: C416.1, R410.2, R412.1, R413.2, U401.8
unnamed: C416.2, R406.1, R412.2, U401.9 (-)
unnamed: R402.2, R407.1, U401.7
unnamed: R405.1, R407.2, U401.6 (-)
unnamed: R411.2, R414.1, U401.14
unnamed: R413.1, R414.2, U401.13 (-)

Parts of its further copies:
C501, C510, C519: 100nF; C_0603
C502, C504, C513, C515: 10uF; C_0805
C503, C511, C512, C514: 100pF; C_0603
C505, C509: 47uF; TantalC_SizeA_EIA-3216_Reflow
C506, C516: 270pF; C_0603
C507, C508, C517, C518: 1nF; C_0603
R501, R502, R510, R511: 237; C_0603
R503, R504, R505, R506, R507, R512, R513, R514: 5k36; C_0603
R508, R509: 100k; C_0603
U501: TLC274; TSSOP-14_4.4x5mm_Pitch0.65mm

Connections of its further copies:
+5VA: C501.2, U501.4 (V+); also elsewhere on the board
/codec/acon3: C505.2, C512.1, R509.1; also elsewhere on the board
/codec/acon4: C509.2, C511.1, R508.1; also elsewhere on the board
/codec/adc5: C503.2, C504.1, C507.1; also elsewhere on the board
/codec/adc6: C502.1, C503.1, C508.1; also elsewhere on the board
/codec/adc7: C514.2, C515.1, C517.1; also elsewhere on the board
/codec/adc8: C513.1, C514.1, C518.1; also elsewhere on the board
BIAS: C510.1, C519.1, U501.3 (+), U501.5 (+), U501.10 (+), U501.12 (+); also elsewhere on the board
GND: C501.1, C507.2, C508.2, C510.2, C511.2, C512.2, C517.2, C518.2, C519.2, R508.2, R509.2, U501.11 (V-); also elsewhere on the board
unnamed: C502.2, R501.1
unnamed: C504.2, R502.1
unnamed: C505.1, R503.2
unnamed: C506.1, R501.2, R504.1, R505.2, U501.1
unnamed: C506.2, R503.1, R504.2, U501.2 (-)
unnamed: C509.1, R506.2
unnamed: C513.2, R510.1
unnamed: C515.2, R511.1
unnamed: C516.1, R510.2, R512.1, R513.2, U501.8
unnamed: C516.2, R506.1, R512.2, U501.9 (-)
unnamed: R502.2, R507.1, U501.7
unnamed: R505.1, R507.2, U501.6 (-)
unnamed: R511.2, R514.1, U501.14
unnamed: R513.1, R514.2, U501.13 (-)

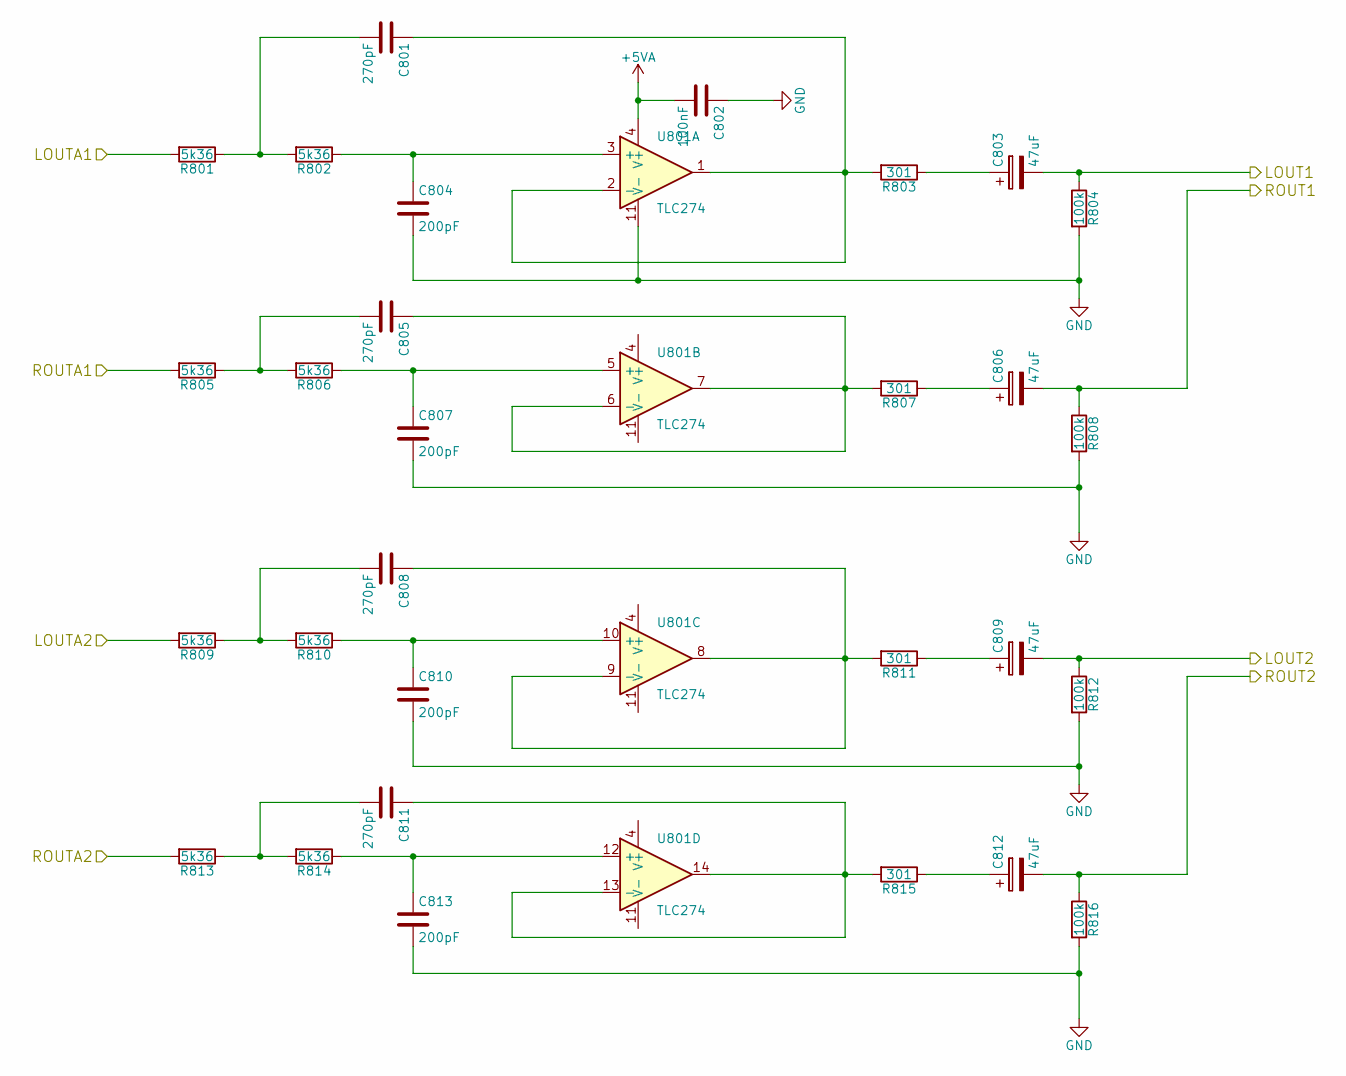
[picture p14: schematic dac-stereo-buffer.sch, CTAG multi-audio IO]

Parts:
C601, C605, C608, C611: 270pF; C_0603
C602: 100nF; C_0603
C603, C606, C609, C612: 47uF; TantalC_SizeA_EIA-3216_Reflow
C604, C607, C610, C613: 200pF; C_0603
R601, R602, R605, R606, R609, R610, R613, R614: 5k36; C_0603
R603, R607, R611, R615: 301; C_0603
R604, R608, R612, R616: 100k; C_0603
U601: TLC274; TSSOP-14_4.4x5mm_Pitch0.65mm

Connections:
+5VA: C602.2, U601.4 (V+); also elsewhere on the board
/codec/acon5: C603.2, R604.1; also elsewhere on the board
/codec/acon6: C606.2, R608.1; also elsewhere on the board
/codec/acon7: C609.2, R612.1; also elsewhere on the board
/codec/acon8: C612.2, R616.1; also elsewhere on the board
/codec/dac1: R601.2; also elsewhere on the board
/codec/dac2: R605.2; also elsewhere on the board
/codec/dac3: R609.2; also elsewhere on the board
/codec/dac4: R613.2; also elsewhere on the board
GND: C602.1, C604.2, C607.2, C610.2, C613.2, R604.2, R608.2, R612.2, R616.2, U601.11 (V-); also elsewhere on the board
unnamed: C601.1, R603.2, U601.1, U601.2 (-)
unnamed: C601.2, R601.1, R602.2
unnamed: C603.1, R603.1
unnamed: C604.1, R602.1, U601.3 (+)
unnamed: C605.1, R607.2, U601.6 (-), U601.7
unnamed: C605.2, R605.1, R606.2
unnamed: C606.1, R607.1
unnamed: C607.1, R606.1, U601.5 (+)
unnamed: C608.1, R611.2, U601.8, U601.9 (-)
unnamed: C608.2, R609.1, R610.2
unnamed: C609.1, R611.1
unnamed: C610.1, R610.1, U601.10 (+)
unnamed: C611.1, R615.2, U601.13 (-), U601.14
unnamed: C611.2, R613.1, R614.2
unnamed: C612.1, R615.1
unnamed: C613.1, R614.1, U601.12 (+)

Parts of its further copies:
C801, C805, C808, C811: 270pF; C_0603
C802: 100nF; C_0603
C803, C806, C809, C812: 47uF; TantalC_SizeA_EIA-3216_Reflow
C804, C807, C810, C813: 200pF; C_0603
R801, R802, R805, R806, R809, R810, R813, R814: 5k36; C_0603
R803, R807, R811, R815: 301; C_0603
R804, R808, R812, R816: 100k; C_0603
U801: TLC274; TSSOP-14_4.4x5mm_Pitch0.65mm

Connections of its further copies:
+5VA: C802.2, U801.4 (V+); also elsewhere on the board
/codec/acon9: C803.2, R804.1; also elsewhere on the board
/codec/acon10: C806.2, R808.1; also elsewhere on the board
/codec/acon11: C809.2, R812.1; also elsewhere on the board
/codec/acon12: C812.2, R816.1; also elsewhere on the board
/codec/dac5: R801.2; also elsewhere on the board
/codec/dac6: R805.2; also elsewhere on the board
/codec/dac7: R809.2; also elsewhere on the board
/codec/dac8: R813.2; also elsewhere on the board
GND: C802.1, C804.2, C807.2, C810.2, C813.2, R804.2, R808.2, R812.2, R816.2, U801.11 (V-); also elsewhere on the board
unnamed: C801.1, R803.2, U801.1, U801.2 (-)
unnamed: C801.2, R801.1, R802.2
unnamed: C803.1, R803.1
unnamed: C804.1, R802.1, U801.3 (+)
unnamed: C805.1, R807.2, U801.6 (-), U801.7
unnamed: C805.2, R805.1, R806.2
unnamed: C806.1, R807.1
unnamed: C807.1, R806.1, U801.5 (+)
unnamed: C808.1, R811.2, U801.8, U801.9 (-)
unnamed: C808.2, R809.1, R810.2
unnamed: C809.1, R811.1
unnamed: C810.1, R810.1, U801.10 (+)
unnamed: C811.1, R815.2, U801.13 (-), U801.14
unnamed: C811.2, R813.1, R814.2
unnamed: C812.1, R815.1
unnamed: C813.1, R814.1, U801.12 (+)

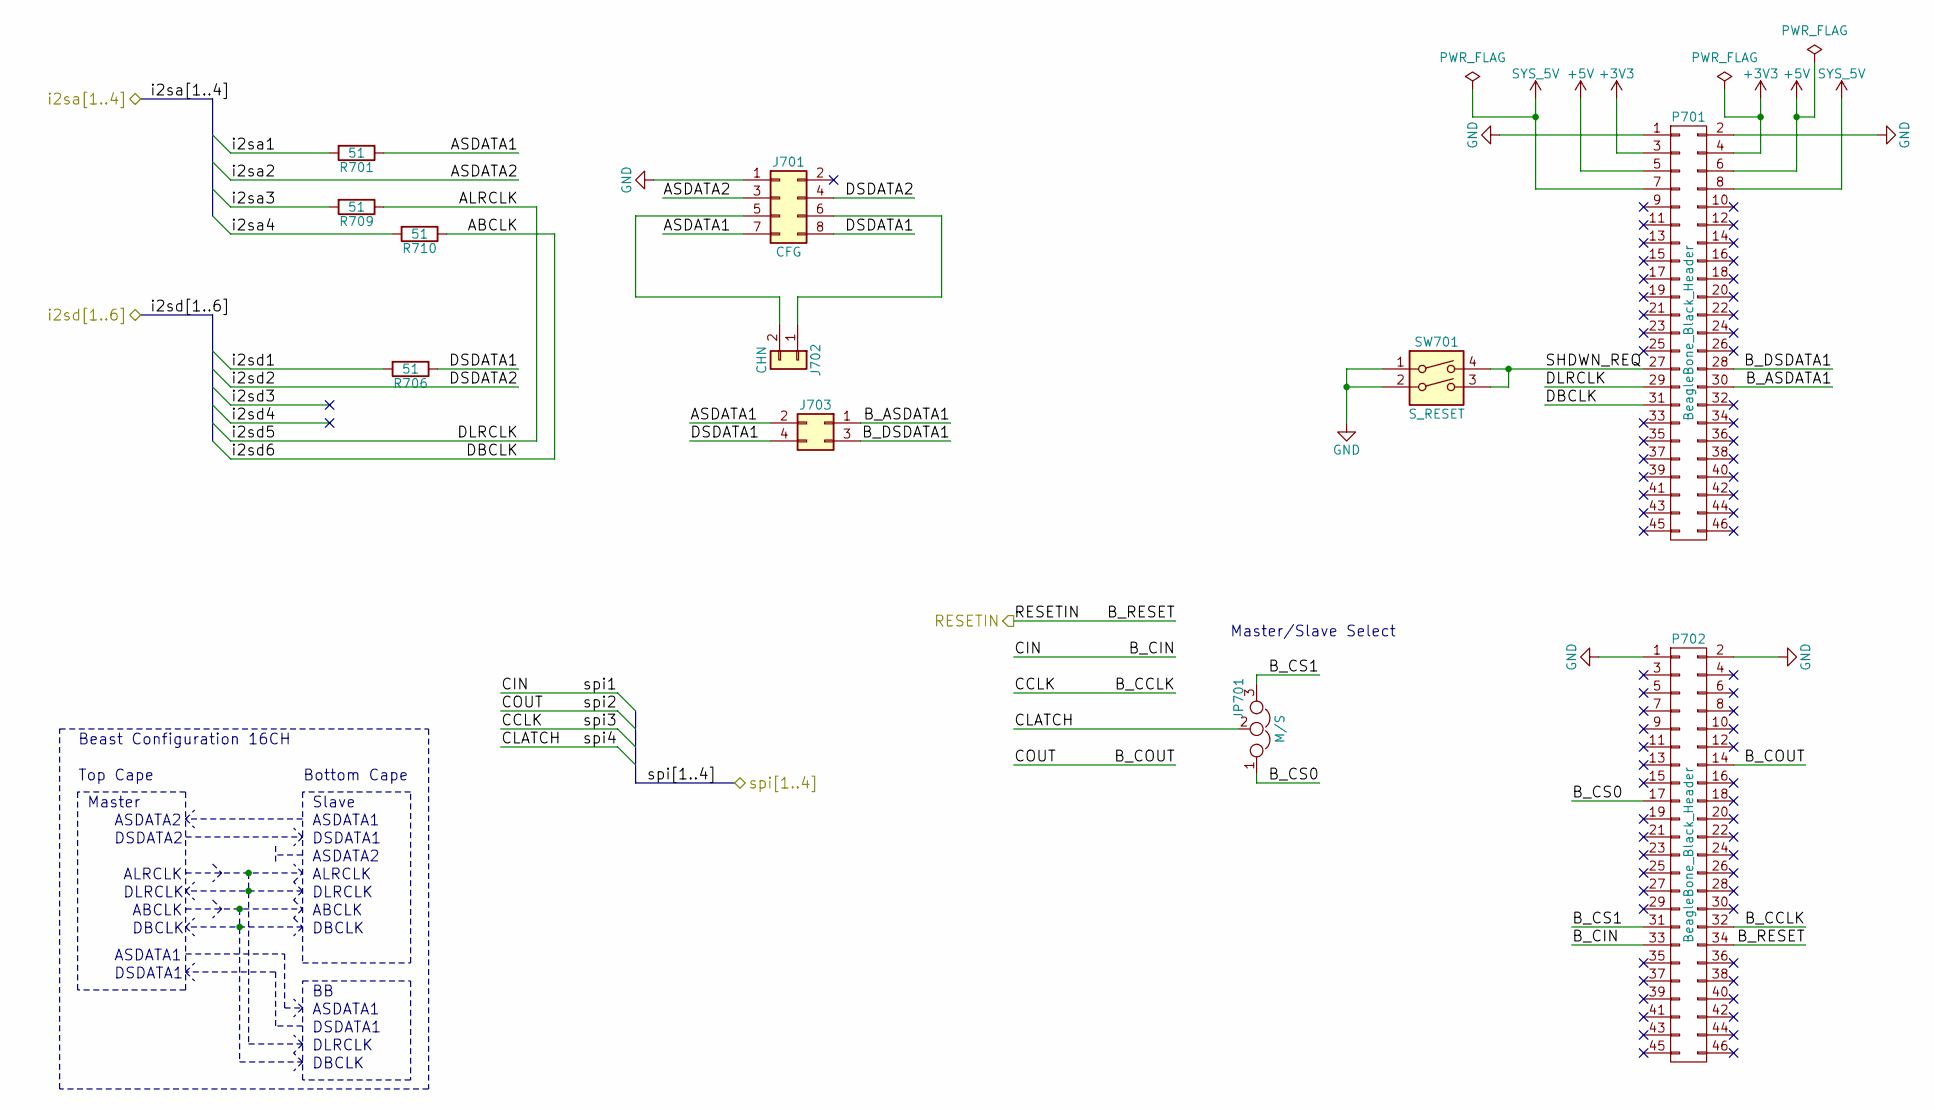
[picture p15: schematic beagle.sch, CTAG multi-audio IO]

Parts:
J701: CFG; Pin_Header_Straight_2x04
J702: CHN; Pin_Header_Straight_1x02
J703: Pin_Header_Straight_1x04
JP701: M/S; Pin_Header_Straight_1x03
P701, P702: BeagleBone_Black_Header; Pin_Header_Straight_2x23
R701, R706, R709, R710: 51; C_0603
SW701: S_RESET; PTS810

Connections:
+3V3: P701.3, P701.4
+5V: P701.5, P701.6; also elsewhere on the board
/codec/beagle/ASDATA1: J701.7, J703.2, R701.1
/codec/beagle/B_ASDATA1: J703.1, P701.30
/codec/beagle/B_CS0: JP701.1, P702.17
/codec/beagle/B_CS1: JP701.3, P702.31
/codec/beagle/B_DSDATA1: J703.3, P701.28
/codec/beagle/DSDATA1: J701.8, J703.4, R706.1
/codec/beagle/RESETIN: P702.34; also elsewhere on the board
/codec/beagle/SHDWN_REQ: P701.27, SW701.3, SW701.4
/codec/i2sa1: R701.2; also elsewhere on the board
/codec/i2sa2: J701.3; also elsewhere on the board
/codec/i2sa3: R709.2; also elsewhere on the board
/codec/i2sa4: R710.2; also elsewhere on the board
/codec/i2sd1: R706.2; also elsewhere on the board
/codec/i2sd2: J701.4; also elsewhere on the board
/codec/i2sd5: P701.29, R709.1; also elsewhere on the board
/codec/i2sd6: P701.31, R710.1; also elsewhere on the board
/codec/spi1: P702.33; also elsewhere on the board
/codec/spi2: P702.14; also elsewhere on the board
/codec/spi3: P702.32; also elsewhere on the board
/codec/spi4: JP701.2; also elsewhere on the board
GND: J701.1, P701.1, P701.2, P702.1, P702.2, SW701.1, SW701.2; also elsewhere on the board
unnamed: J701.5, J702.2
unnamed: J701.6, J702.1
SYS_5V: P701.7, P701.8; also elsewhere on the board

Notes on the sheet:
Master/Slave Select
Master
Slave
ASDATA2
ASDATA1
DSDATA2
DSDATA1
ALRCLK
DLRCLK
ABCLK
DBCLK
Beast Configuration 16CH
Bottom Cape
Top Cape

Board: 4 copper layers, 177 parts (0 on the bottom side), 127 nets, no tracks yet.

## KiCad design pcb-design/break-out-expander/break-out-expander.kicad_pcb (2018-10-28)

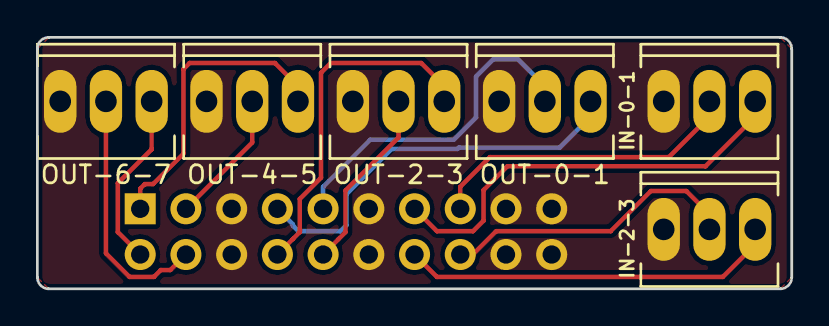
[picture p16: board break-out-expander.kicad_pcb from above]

Board: 2 copper layers, 41.9 x 14.0 mm, 7 parts (1 on the bottom side), 13 nets.

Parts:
I/O: Pin_Header_Straight_2x10
IN-0-1, IN-2-3: Socket_MOLEX-KK-RM2-54mm_Lock_3pin_straight
OUT-0-1, OUT-2-3, OUT-4-5, OUT-6-7: Socket_MOLEX-KK-RM2-54mm_Lock_3pin_straight

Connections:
GND: I/O.5, I/O.6, I/O.11, I/O.12, I/O.17, I/O.18, I/O.19, I/O.20, IN-0-1.1, IN-2-3.1, OUT-0-1.1, OUT-2-3.1, OUT-4-5.1, OUT-6-7.1
unnamed: I/O.15, IN-0-1.2
unnamed: I/O.13, IN-0-1.3
unnamed: I/O.16, IN-2-3.2
unnamed: I/O.14, IN-2-3.3
unnamed: I/O.9, OUT-0-1.2
unnamed: I/O.7, OUT-0-1.3
unnamed: I/O.10, OUT-2-3.2
unnamed: I/O.8, OUT-2-3.3
unnamed: I/O.3, OUT-4-5.2
unnamed: I/O.1, OUT-4-5.3
unnamed: I/O.4, OUT-6-7.2
unnamed: I/O.2, OUT-6-7.3

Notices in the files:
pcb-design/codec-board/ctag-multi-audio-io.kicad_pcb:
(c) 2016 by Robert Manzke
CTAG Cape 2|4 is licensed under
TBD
